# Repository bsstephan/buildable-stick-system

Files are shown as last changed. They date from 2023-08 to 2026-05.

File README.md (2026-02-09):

# The Buildable Stick System

Files for 3D printing and building an arcade stick enclosure.

Have you ever wanted to conjure your own arcade stick out of the ether (well, plastic), or to prototype a new layout or
design before sending it to a custom builder? Do you just love having your space filled with arcade stick enclosures,
because you keep making different variants, colorways, and so on? Or do you simply want a good stick on the cheap, and
know someone or a library with a 3D printer? The Buildable Stick System may be the project for you!

**Join the project IRC channel: [#buildable-stick-system @
Randomus](https://webirc.randomus.net/#buildable-stick-system)!**

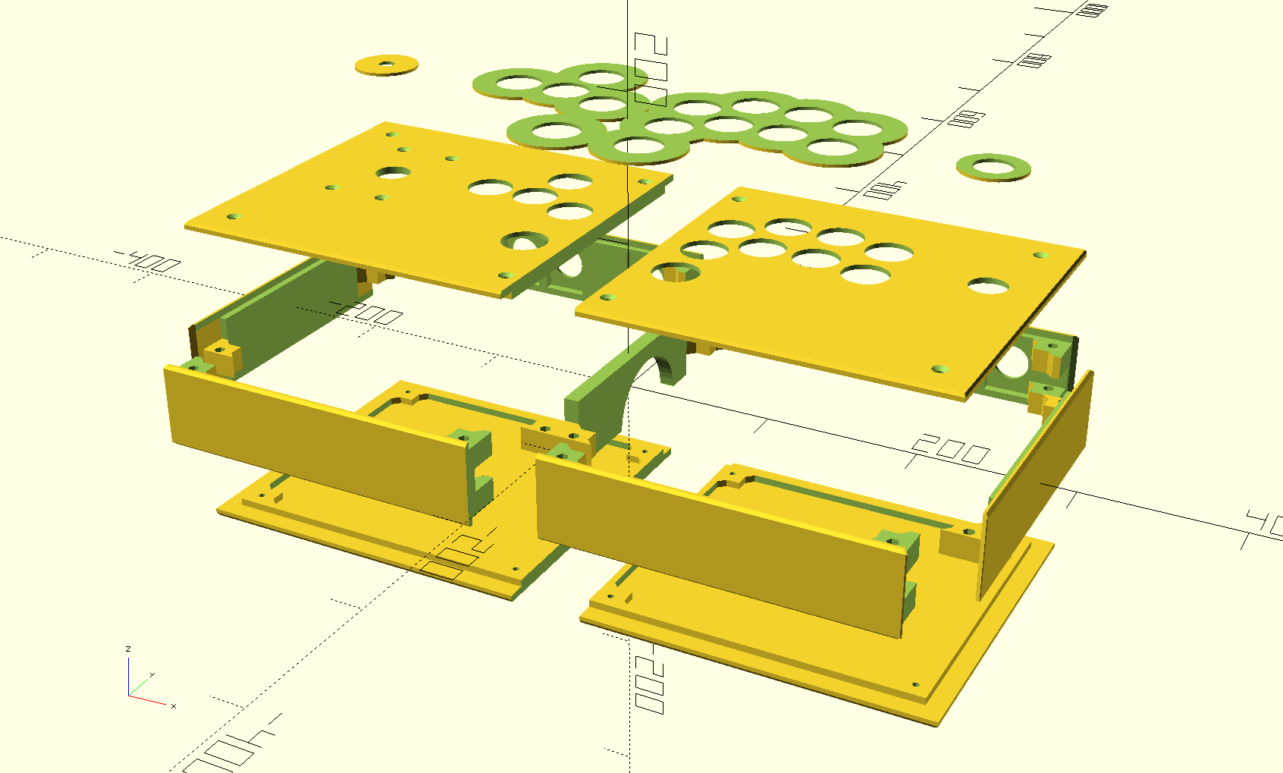
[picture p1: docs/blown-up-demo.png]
An example of stick components displayed in OpenSCAD


[OpenSCAD-based illustration of how the components for an overhang panel-based stick fit together.]

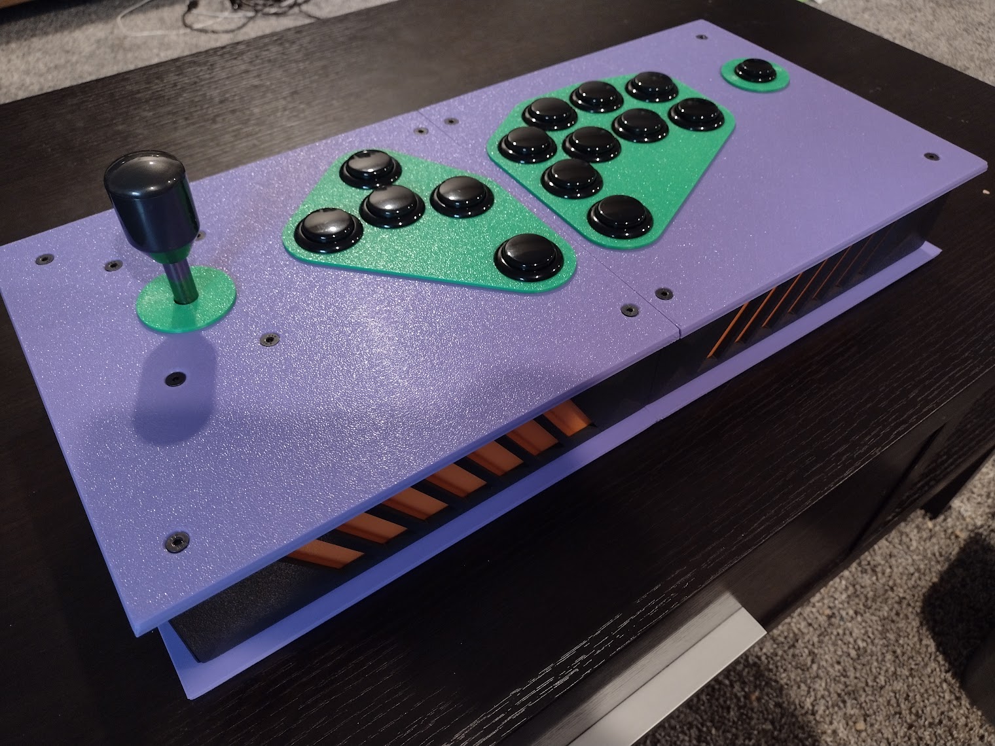
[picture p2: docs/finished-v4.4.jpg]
A photo of a completed stick


[Photo of a completed overhang panel-based stick.]

Originally an attempt to make a couple customized STL files for the [OpenStickCommunity Fightstick
Case](https://github.com/OpenStickCommunity/Hardware/tree/main/Fightstick%20Case), the changes ballooned to fit my
design and became incompatible with that project's components. This should be considered a different project with some
similar DNA, but to stress again, it could not have been done without that project as a guide star. See **Attribution**.

## Designing

No particular arcade stick design is prescribed by this project, instead, SCAD files are provided to choose desired
component objects or create new ones. The OpenSCAD language is essentially a functional programming language, making it
it easy to reuse, alter, and compose objects. If you do not see the object you would like, you can likely create it by
starting with an existing object and constructing what you'd like with new or existing components.

## Usage of Parts

There are a lot of parts to pick from, but there are some structural variants to pay attention to; here's some help
about what the types of parts are and how to use them:

* `frames/`
    * `complete/` --- these are the four walls of the frame as one piece, in a couple variations for combining into
      larger arcade sticks. They are simple to assemble, but you have fewer modularity/customization options, and they
      are harder to print because the physics of the material cooling will probably pull the corners up. They also need
      supports, since the top and bottom of the frame both have trays for panels to go into. Use at your own risk.
    * `pieces/` these are the same four walls (generally speaking) as in the complete frames above, broken out into
      modular pieces to print separately. Because they are separate pieces, you can mix and match colors, and you can
      lay them all face down on the print surface for better adhesion and surface patterns. There are also variants
      here, the "windowed" pieces, for doing two-tone variants and that kind of thing. There are also frame walls pulled
      out to create MCZ TE-style extended sides. There is an interconnect that stands in for the joined inner wall
      between boxes of the overall unit. You need this if you are combining multiple sets of walls, e.g. for a
      two-panel-long stick.
* `panels/`
    * `inset/` --- various panels, all of the same size, that fit into and flush with the frame, making the arcade stick
      top or bottom. Aside from using up a bit of the space for components inside the frame, come with no downsides ---
      they print easily and are a pretty simple shape to tweak and remix.
    * `overhang/` --- overhang panels have their plane extending over the edge of the frame, creating a bit of a
      sandwich look. This is mostly an aesthetic choice, but they sit higher in the frame as well, the main panel being
      over/under the frame rather than within it. This extra space is useful for taller levers. The only downside to
      these is that they aren't as reusable as the inset panels, since the inset panels can go anywhere, but the
      overhang panels must be designed to not overlap with other overhang panels, so you might have to make more custom
      variants depending on where you put things.
* `plates/`
    * Flat pieces used for cosmetic or connective reasons --- decorative plates for top buttons and similar to give
      more color variance and some layers to the arcade stick, some very simple dustwashers, plates that fit rocker
      switches and the like in Neutrik D or 20mm holes, and a lever mount spacer for getting your lever shaft at the
      desired height. You don't *need* any of these, but you'll probably use a few.
* `misc/`
    * Pieces that I haven't organized better (yet) --- odd things and scratch ideas, mostly. There are some decorative
      corners for a bit more height/nicer seams, a sleeve to make smaller hex spacers fit in the hole as they're
      supposed to, things of that nature.
* `extras/`
    * Various experiments and things not directly related to making an arcade stick. At time of writing, there's a
      couple pieces for a little stand for the stick, solely for vanity purposes.
        * `bss-ae/` --- these are pieces for an arcade control panel that fits on the Qanba 2009. See the docs in that
          directory for details.

Feel free to request or contribute to more objects. Additional documentation regarding assembling the stick is available
in `docs/assembly-and-tips.md`.

## Printing

These items all fit on a 256mm^2 print bed; I use a Bambu Lab P1P based on what I've learned from the
OpenStickCommunity. Standard settings seem sufficiently sturdy, but see `docs/printing-and-materials.md` for more
thoughts and settings based on my tinkering with prints.

## Assembling

What you'll need beyond these objects:

* An arcade stick board (I recommend [TheTrain's RP2040 Advanced Breakout
  Board](https://github.com/OpenStickCommunity/Hardware/tree/main/RP2040%20Advanced%20Breakout%20Board))
    * 4 M3 8mm hex bolts to secure the PCB to a panel
* Per frame and panel combo:
    * 4 45mm M4 hex brass standoffs (or equivalent)
    * 8 M4 countersunk hex bolts
        * Overhang panels should use 12-16mm length bolts since they are taller
        * Inset panels should probably use 8-12mm bolts --- some standoffs aren't threaded the whole way, making 16mm
          too long to go flush
        * If making the 45mm standoffs from multiple smaller ones, make sure they have enough length to take your bolts!
* Per frame connection point (only necessary if you are using complete frames and not frame pieces):
    * 8 16mm M4 bolts
    * 8 M4 flange nuts
* For a lever:
    * 4 12-16mm M4 countersunk hex bolts
    * 4 M4 flange nuts
* For Neutrik D connections:
    * 2 10mm M3 hex bolts
    * 2 M3 flange nuts
* Buttons and levers as desired
* Wiring as required

## Rough Costs

This is a rough estimate of the cost to produce one of these sticks, assuming a usual 2-frame design and layout.
Filament masses from Bambu Studio estimates, using Bambu PLA Basic, 20% gyroid infill and 3 wall loops.

* Left and right frame: **$10.42 USD** (208.50g each, as of 2024-02-22)
* Left and right (inset) top panels: **~$6.40 USD** (~128g each, as of 2024-02-22)
* Left and right (non-overhang) bottom panels: **$6.80 USD** (135.99g each, as of 2024-02-22)
* Miscellaneous mounting plates, decorative plates, etc.: **~$1.83 USD** (~73g, as of 2024-02-22)
* 8 16mm M4 bolts to connect the frames: **$0.72 USD** (you can get a pack of 100 on Amazon for $9, as of 2023-09-12)
    * These are only necessary if you are using the whole frames, but as a heads up, the material cost of the
      pieces-based interconnect piece costs around $1, so it's roughly a wash since that's also a frame wall.
* 8 M4 flange nuts to connect the frames: **$0.68 USD** (you can get a pack of 100 on Amazon for $8.50, as of 2023-09-12)
* 4 10mm M3 bolts to connect Neutrik D plates to frames: **$0.40 USD** (you can get a pack of 100 on Amazon for $10, as
  of 2023-09-12)
* 4 M3 flange nuts to connect Neutrik D plates to frames: **$0.34 USD** (you can get a pack of 100 on Amazon for $8.50,
  as of 2023-09-12)
* 8 45mm M4 standoffs to connect panels to frames: **$2.40 USD** (you can get a pack of 10 on AliExpress for $3, as of
  2023-09-12)
    * You could 3D print these too, but you're probably better off with brass ones as they give some weight to the
      stick anyway
    * You can also use a shorter length with longer bolts, or combine multiple standoffs, if either of those yield better
      prices
* 8 16mm M4 bolts to connect top panels to frames: **$0.72 USD** (you can get a pack of 100 on Amazon for $9, as of
* 8 12mm M4 bolts to connect bottom panels to frames: **$0.72 USD** (you can get a pack of 100 on Amazon for $9, as of
  2023-09-12)

With an enclosure coming in around $31, depending on your choices --- say, ~$30 for TheTrain's RP2040 Advanced Breakout
Board, ~$60 for Sanwa buttons and a lever, and ~$20 for miscellaneous connectors and wiring --- you can put a
full-featured controller with an open source foundation together for around $140. Reducing wall and infill settings
will probably save you around $5 of material, and you can probably decide what you want to do from there.

## FAQ

### I get a bunch of warnings on not being able to include files when I open them in OpenSCAD, what do I do?

OpenSCAD pathing is relative to the current working directory by default, which is probably not the `src/` directory.
When you start OpenSCAD, you must either start it from inside the project's `src/` directory, or point it at the path to
the source files via e.g. `OPENSCADPATH=path/to/buildable-stick-system/src/ openscad`.

See <https://en.wikibooks.org/wiki/OpenSCAD_User_Manual/Include_Statement>.

## Miscellany

See the `/docs/` directory for more thoughts too scattered for this document.

## Issues and Limitations

This is a living repository, and as such, there are likely issues with the objects, known or otherwise.
These issues may be fixed in the future; see `TODO.md` for details.

## Development and Contributing

Improvements, variants, new layouts, novel ideas, and etc. are all welcome.

These files are suitable for previewing and rendering in OpenSCAD. They may also work in FreeCAD and perhaps other
software, but they are developed in OpenSCAD, so YMMV otherwise.

This project is hosted at [my personal Git site](https://git.incorporeal.org/bss/buildable-stick-system), but people are
more likely to want to interact with [the GitHub mirror](https://github.com/bsstephan/buildable-stick-system). Feel free
to use either.

I'm reachable on the fediverse, over email, or on Discord, but if you're looking for an option I prefer, I maintain an
IRC channel, `#buildable-stick-system`, on [my IRC network, Randomus](https://randomus.net/) if you would like a place
to hang out and discuss issues and features and whatnot.

## Attribution

### Author and Licensing

Written by and copyright Brian S. Stephan (<bss@incorporeal.org>).

The Buildable Stick System is free software: you can redistribute it and/or modify it under the terms of the GNU General
Public License as published by the Free Software Foundation, either version 3 of the License, or (at your option) any
later version.

The Buildable Stick System is distributed in the hope that it will be useful, but WITHOUT ANY WARRANTY; without even the
implied warranty of MERCHANTABILITY or FITNESS FOR A PARTICULAR PURPOSE. See the GNU General Public License for more
details.

You should have received a copy of the GNU General Public License along with the Buildable Stick System. If not, see
<https://www.gnu.org/licenses/>.

### Lineage

Inspired by the incredible work of [TheTrain](https://github.com/TheTrainGoes) on the [OpenStickCommunity Fightstick
Case](https://github.com/OpenStickCommunity/Hardware/tree/main/Fightstick%20Case), itself based on the incredible work
by [Dash n'Mash](https://twitter.com/Dash_xx_Mash?s=20). Original work Copyright 2023 TheTrain, [licensed under CC BY
4.0](https://creativecommons.org/licenses/by/4.0/).

Made possible by the amazing efforts of [slagcoin](https://www.slagcoin.com/).

### Distributing BSS Sticks

Under the terms of the GPLv3, you must inform the receiver of the "object code" of their rights under the GPLv3. This is
a bit of a gray area for physical objects, but likely applies to distribution of modified or unmodified STL, STEP, etc.
files at a minimum. The easiest way to satisfy the GPLv3 in either situation is to provide a link to the source code
(either the unmodified mainline project, or your copy, with modifications listed in a "prominent notice"); something
like the below should suffice in either electronic or printed form:

> This arcade stick is part of the Buildable Stick System, version X.Y.Z; the source code to this program is available
> under the terms of the GNU General Public License, at [LINK].

## Gallery

More photos.

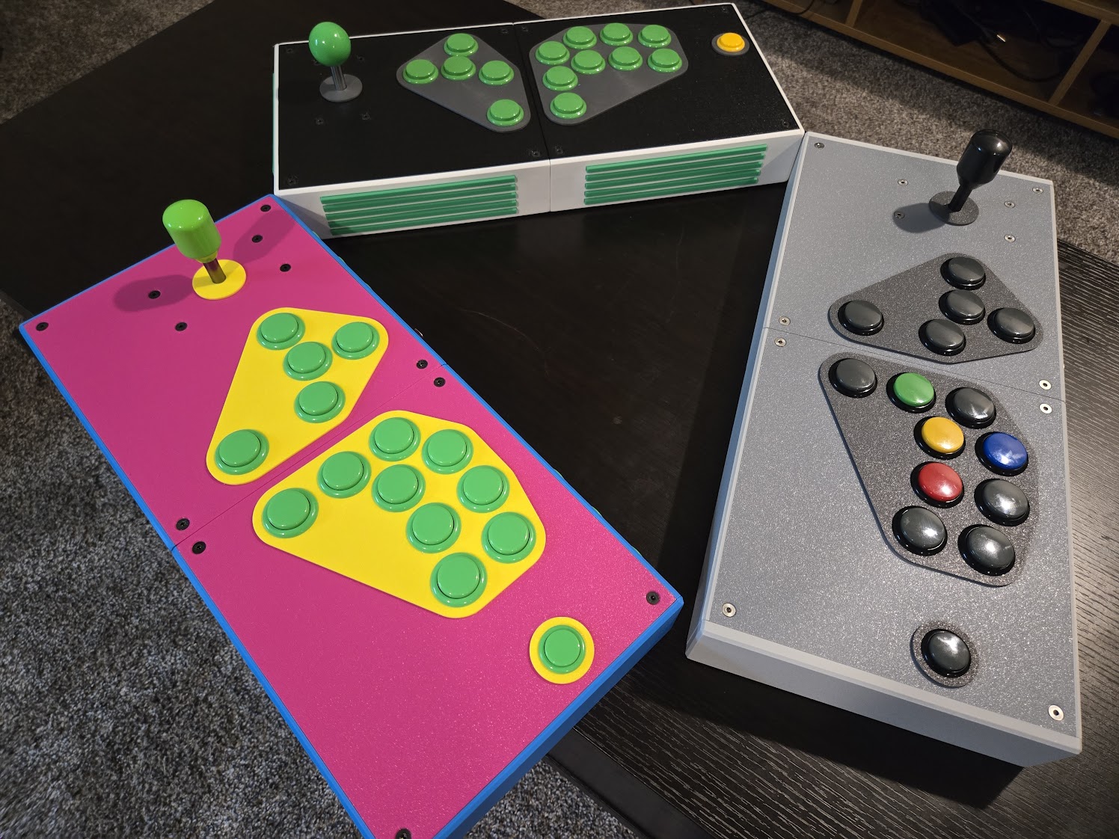
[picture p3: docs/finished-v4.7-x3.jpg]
A photo of three completed sticks


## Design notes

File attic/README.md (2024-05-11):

# The Attic

This directory includes abandoned pieces that I'd like to revisit some time, but I cannot support or recommend using
as-is. Print at your own caution, or better yet, maybe fix them!

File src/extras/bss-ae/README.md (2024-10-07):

# BSS Arcade Edition

Pieces for mounting to a Qanba 2009 in order to create the Buildable Stick System - Arcade Edition.

## Pieces

* 4 `interconnect-x` --- creating the internal support for joining two rows of panels
* 6 `frames/pieces/interconnect` --- (core project) the standard piece for joining two+ columns of panels
* 4 `extended-side-no-back` --- the extended side pieces, flush on the back to connect to each other
* 4 `frames/pieces/extended/front-or-back` --- (core project) the front extended piece
* 2 `extended-back` --- a small piece that fits into the Qanba 2009 "lip" for running cables
* 1 `extended-back-left-mount`
* 1 `extended-back-right-mount` --- extended back pieces that can be mounted to the Qanba 2009 base
* 1 `panel-front-left-mount`
* 1 `panel-front-right-mount` --- blank panels that can be mounted to the Qanba 2009 base
* 6 `panels/inset/panel` --- the rest of the bottom panels
* 4 `panels/inset/` panels of your choice for the front controls
* 2 `panel-three-aux-buttons` --- for aux controls in the back row
* 2 `panel-three-aux-buttons-and-rocker-hole` --- for aux controls and the wired rocker in the back row
* 4 `decorative-plate-aux-control-tight-three-button-cluster` --- for decorating the aux control clusters
* 4 `src/misc/` decorative plates of your choice for the front controls, and similar miscellany
* 4 `mount-spacer` --- making a flush mount between the enclosure and the base

## Hardware

* 32 45mm M4 hex brass standoffs (or equivalent) for each panel/frame compartment
* 64 8-12mm M4 countersunk hex bolts for attaching panels to the compartments
* 4 8-12mm M3 hex bolts and 4 M3 flange nuts for attaching rocker switches to the back panels
* 4 40mm M6 bolts for connecting the enclosure to the base
* 4 M6 flange nuts

## Components

* 2 controller boards, e.g. the RP2040 Advanced Breakout Board
* buttons and/or levers as desired
* necessary wiring

For the rest of the build (e.g. mounting a level to a panel), see the core README.

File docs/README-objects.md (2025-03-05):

# The Buildable Stick System

Files for 3D printing an arcade stick. See `README.md` for the core documentation, this file is specific to distributed
objects.

## Attribution

### Author and Licensing

Written by and copyright Brian S. Stephan (<bss@incorporeal.org>).

These arcade stick parts are from the Buildable Stick System; the source code to this program is available under the
terms of the GNU General Public License, at:

* <https://github.com/bsstephan/buildable-stick-system>, or
* <https://git.incorporeal.org/bss/buildable-stick-system>

See the tags/releases for the version of the source code corresponding to the STLs you received.

The Buildable Stick System is free software: you can redistribute it and/or modify it under the terms of the GNU General
Public License as published by the Free Software Foundation, either version 3 of the License, or (at your option) any
later version.

The Buildable Stick System is distributed in the hope that it will be useful, but WITHOUT ANY WARRANTY; without even the
implied warranty of MERCHANTABILITY or FITNESS FOR A PARTICULAR PURPOSE. See the GNU General Public License for more
details.

You should have received a copy of the GNU General Public License along with the Buildable Stick System. If not, see
<https://www.gnu.org/licenses/>.

### Lineage

Inspired by the incredible work of [TheTrain](https://github.com/TheTrainGoes) on the [OpenStickCommunity Fightstick
Case](https://github.com/OpenStickCommunity/Hardware/tree/main/Fightstick%20Case), itself based on the incredible work
by [Dash n'Mash](https://twitter.com/Dash_xx_Mash?s=20). Original work Copyright 2023 TheTrain, [licensed under CC BY
4.0](https://creativecommons.org/licenses/by/4.0/).

Made possible by the amazing efforts of [slagcoin](https://www.slagcoin.com/).

### Distributing BSS Sticks

Under the terms of the GPLv3, you must inform the receiver of the "object code" of their rights under the GPLv3. This is
a bit of a gray area for physical objects, but likely applies to distribution of modified or unmodified STL, STEP, etc.
files at a minimum. The easiest way to satisfy the GPLv3 in either situation is to provide a link to the source code
(either the unmodified mainline project, or your copy, with modifications listed in a "prominent notice"); something
like the below should suffice in either electronic or printed form:

> This arcade stick is part of the Buildable Stick System, version X.Y.Z; the source code to this program is available
> under the terms of the GNU General Public License, at [LINK].

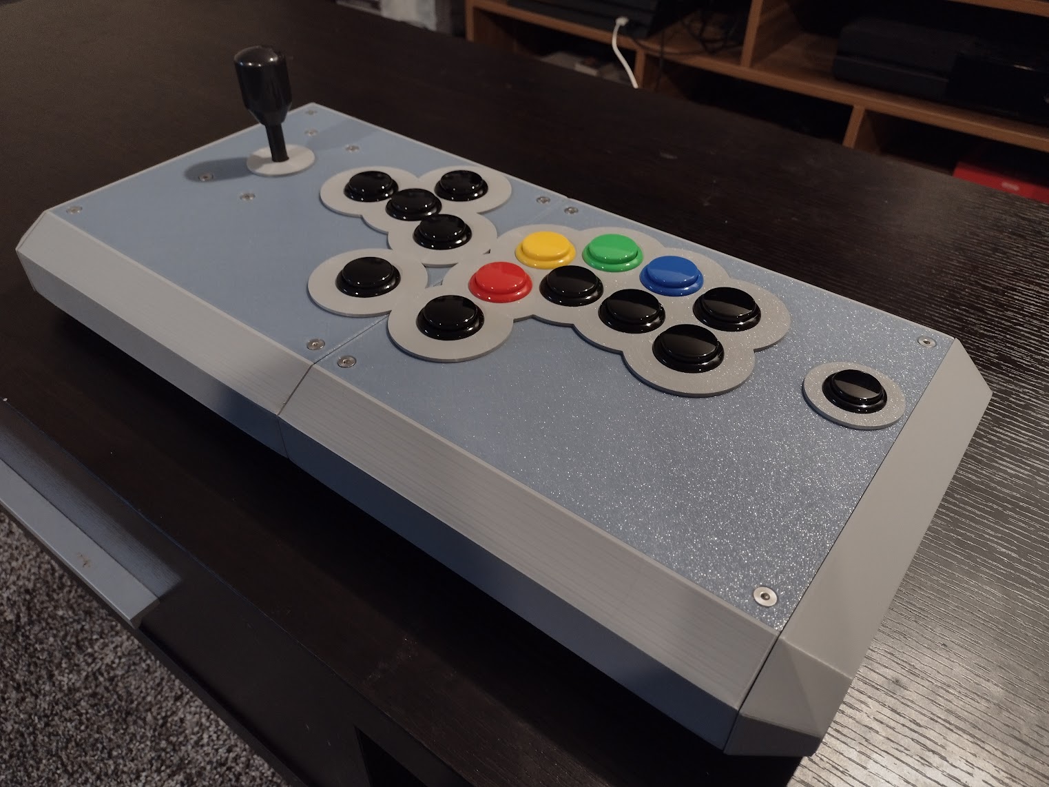
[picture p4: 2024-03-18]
docs/finished-v4.2.jpg

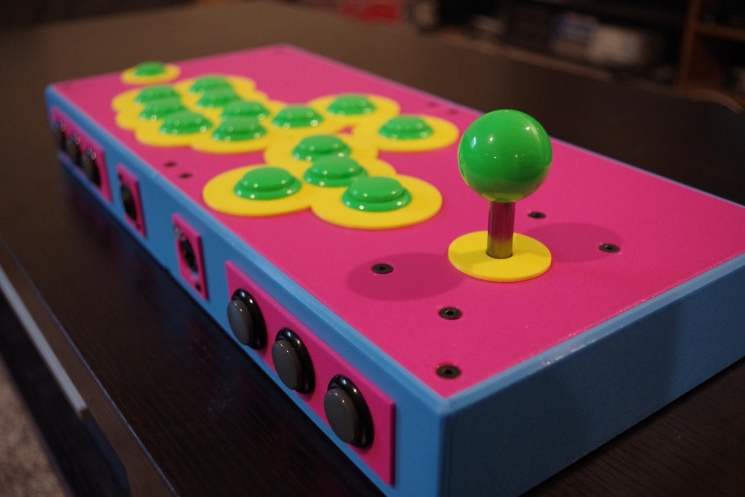
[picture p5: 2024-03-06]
docs/finished-v4.1.jpg

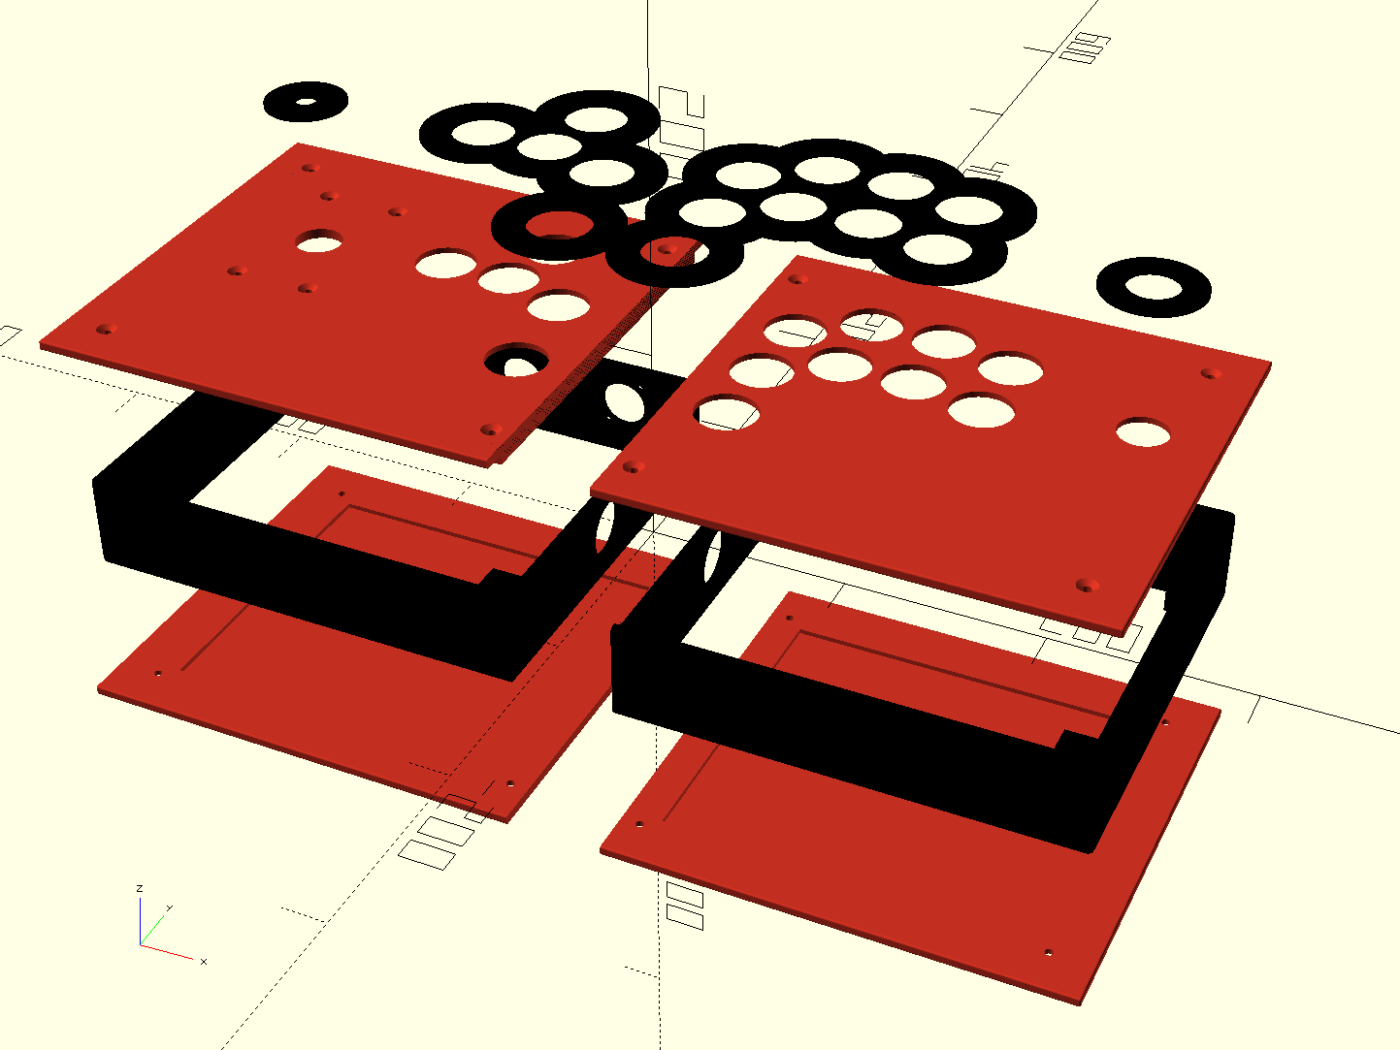
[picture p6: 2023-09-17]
docs/two-panel-example-v3.png

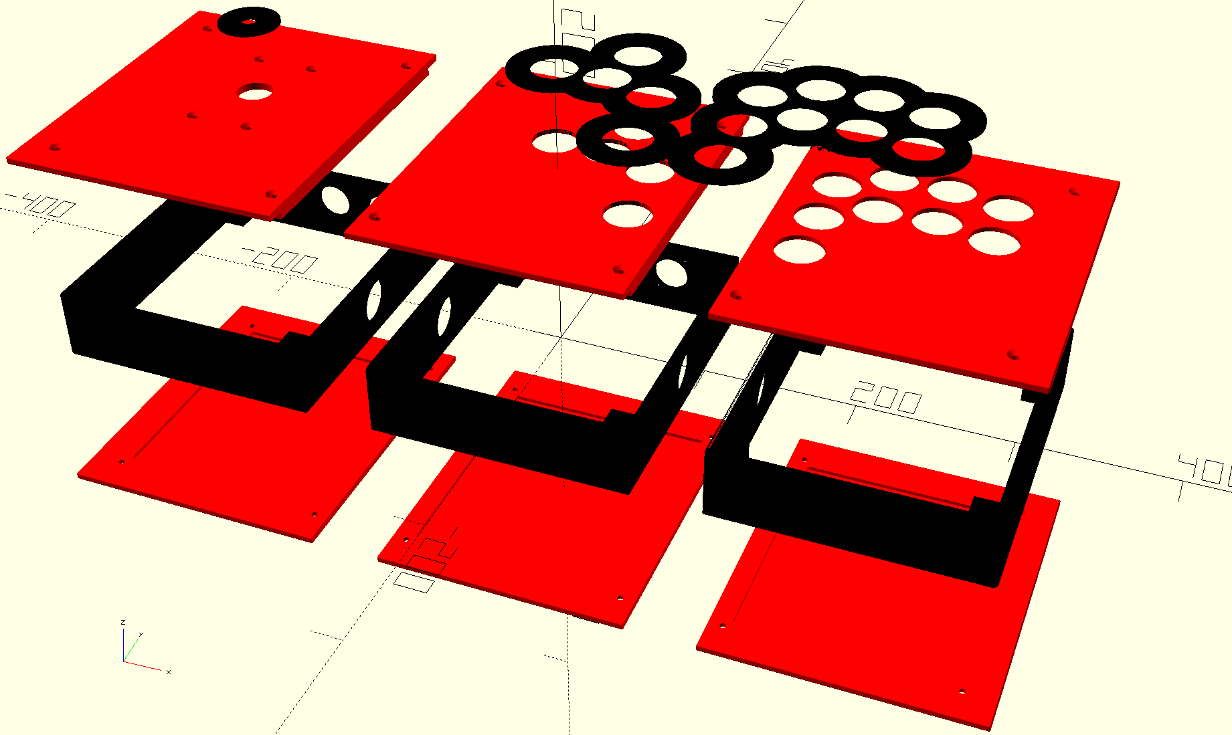
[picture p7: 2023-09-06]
docs/three-panel-example-v2.png

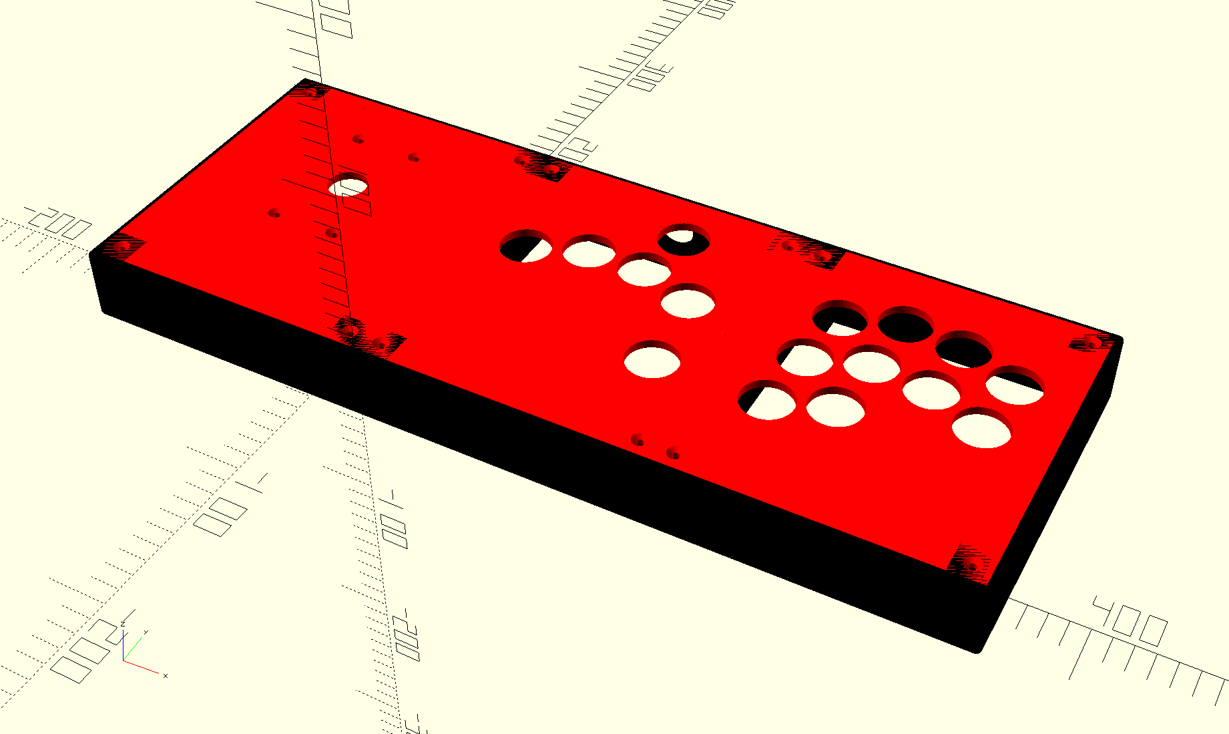
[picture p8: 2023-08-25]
docs/three-panel-example.png

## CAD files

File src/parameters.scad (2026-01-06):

/*
 * SPDX-FileCopyrightText: © 2023 Brian S. Stephan <bss@incorporeal.org>
 * SPDX-License-Identifier: GPL-3.0-or-later
 */


// CONNECTION POINT SIZES


// adjustments
hole_tolerance = 0.15;

// M2
m2_screw_selftap_radius = 0.95;

// M3
m3_screw_selftap_radius = 1.3;

// M4
m4_bolt_radius = 2 + hole_tolerance;
m4_bolt_countersink_radius = 6.1 + hole_tolerance;
m4_bolt_hex_exterior_radius = 3.6 + hole_tolerance;

// M6
m6_bolt_radius = 3 + hole_tolerance;

// 24mm button
small_button_radius = 12 + hole_tolerance;

// 30mm button
big_button_radius = 15 + hole_tolerance;

// carve out space around buttons for screw-in nuts
// slagcoin has screw-in nut diameter at 36mm for 30mm buttons, 29.5 for 24mm buttons
// radius + value below should leave space for the nut and for fingers to grab the nut
button_radius_connector_space = 5;

// standard lever hole
lever_plate_hole = 12;

// neutrik D screw holes
neutrik_d_screw_radius = 1.6 + hole_tolerance;
neutrik_d_radius = 12 + hole_tolerance;


// ELEMENT DIMENSIONS


// JLF mount dimensions
lever_mount_x = 53;
lever_mount_y = 95;
lever_mount_z = 2;

// base frame box. reminder: inside top and bottom (including mounts) are chopped by panel_z for plates
frame_x = 233;
frame_y = 208;
frame_z = 57;

// depth of the "lip" of the frame that the top plate sets into/supports the overhang
frame_wall = 4;

// top plate, which can either be the whole plate ("inset") or the mounting frame for a plate that overhangs
panel_x = frame_x - (frame_wall * 2);
panel_y = frame_y - (frame_wall * 2);
panel_z = 5;

// some dimensions for frame pieces, useful in doing some intersections and chopping
frame_piece_x_x = frame_x - (frame_wall * 2);	// essentially panel_x, yes
frame_piece_y_y = frame_y;			// the whole y of the frame, yes

// degree to which the extended frame pieces stick out from the end of the frame
frame_extension_x = 25;
frame_extension_y = 25;

// this sinks the bottom and top of the frame inward a bit, and is used to math out two shapes
// when creating the frame box / overhang panel
frame_bevel_height = 1.25;
overhang_panel_bevel_height = 1;

frame_center_to_neutrik = 70;

// width of the column in the frame corners to support the hex bolt
frame_mount_column_width = 20;

// per neutrik (mm)
neutrik_panel_thickness = 3;

// inside the frame
inner_frame_z = frame_z - (panel_z * 2);

// "windowed" pieces chop out the inner wall of the frame as a separate piece in order
// to print it a different color/way/style. to improve friction fit, it is only the below
// value scale of the whole wall, so that the rest of the wall is retained on the outer
// piece, which helps clamp the two together (and helps the panels clamp it all)
inner_frame_z_decorative_scale = 0.95;

// how much the top plate x/y is expanded to overhang the frame
// note that this is relative to the top plate (so the wall is added back)
panel_overhang_amount = 8.5;
overhang_panel_x = panel_x + (frame_wall * 2) + (panel_overhang_amount * 2);
overhang_panel_y = panel_y + (frame_wall * 2) + (panel_overhang_amount * 2);

panel_to_frame_point_offset = 10;
panel_to_frame_point_x = (panel_x/2) - panel_to_frame_point_offset;
panel_to_frame_point_y = (panel_y/2) - panel_to_frame_point_offset;

// frame interior that supports the top plates
panel_support_width = 5;

// additional button radius for decorative panels, etc.
decorative_radius_scale = 1.75;
jumbo_decorative_radius_scale = 2;

// decorative wall cutout parameters
// thicker than the actual base wall to account for the longish pieces
wall_cutout_depth = frame_wall * 3;

// decorative slash parameters
slash_inner_displacement = 10;
slash_width = 15;
slash_height = frame_z-panel_z*3;

// dustwasher parameters
jlf_dustwasher_radius = 19;
jlf_shaft_inner_radius = 4.55;

lsx_nobi_dustwasher_radius = jlf_dustwasher_radius;
lsx_nobi_shaft_inner_radius = 5;

shaft_position_tolerance = 2;

// stand dimensions to display a stick
stand_x = 5;
stand_y = frame_z;
stand_z = 15;

// oled cutout stuff
ssd1306_x = 23;
ssd1306_y = 12;
ssd1306_z = 1;
adafruit_pid_326_oled_ssd1306_cutout_x = 30;
adafruit_pid_326_oled_ssd1306_cutout_y = 32;


// LAYOUTS


sega_2p_column_2_offset = 30.5;
sega_2p_column_3_offset = sega_2p_column_2_offset + 36;
sega_2p_column_4_offset = sega_2p_column_3_offset + 36;
sega_2p_column_5_offset = sega_2p_column_4_offset + 36;

// this offset is from the left edge of the panel
sega_2p_column_1_left_panel_edge_offset = 28.06;

dir_arc_30mm_column_2_offset = 33.8;
dir_arc_30mm_column_3_offset = dir_arc_30mm_column_2_offset + 34.8;
dir_arc_30mm_row_2_offset = 57.2;
dir_arc_30mm_row_3_offset = dir_arc_30mm_row_2_offset + 12.9;
dir_arc_w_30mm_row_4_offset = dir_arc_30mm_row_3_offset + 34.5;

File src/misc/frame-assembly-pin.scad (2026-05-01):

/* Fit a pin for the assembly holes.
 *
 * SPDX-FileCopyrightText: © 2026 Brian S. Stephan <bss@incorporeal.org>
 * SPDX-License-Identifier: GPL-3.0-or-later
 */
include <parameters.scad>
include <components.scad>

// adjust the pin to have a good friction fit based on parameters
pin_fit_scale = ((m4_bolt_hex_exterior_radius-hole_tolerance)*2)/(m4_bolt_hex_exterior_radius*2);

module frame_assembly_pin() {
	difference() {
		scale([pin_fit_scale, pin_fit_scale, 0.95]) resize([0, 0, inner_frame_z]) frame_hex_bolt_hole();
		scale([0.8, 0.8, 1]) resize([0, 0, inner_frame_z]) m4_hole();
	}
}


frame_assembly_pin();

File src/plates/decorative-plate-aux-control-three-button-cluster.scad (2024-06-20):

/*
 * SPDX-FileCopyrightText: © 2023 Brian S. Stephan <bss@incorporeal.org>
 * SPDX-License-Identifier: GPL-3.0-or-later
 */

include <parameters.scad>
include <components.scad>
use <neutrik-d-plate.scad>

module aux_control_three_button_cluster_decorative_plate() {
	difference() {
		hull() {
			translate([-44, 0, 0]) neutrik_d_plate();
			translate([44, 0, 0]) neutrik_d_plate();
		}
		translate([0, 0, -10]) aux_control_three_button_cluster();
	}
}

aux_control_three_button_cluster_decorative_plate();

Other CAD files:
src/extras/bss-ae/decorative-plate-aux-control-tight-three-button-cluster.scad
attic/extras/tower-of-hovering-power-mount.scad
demo/all-together-demo-extended-with-windows.scad
demo/all-together-demo-extended.scad
demo/all-together-demo-solo.scad
demo/all-together-demo.scad
demo/blown-up-demo.scad
src/bottom-panel-no-overhang.scad
src/bottom-panel-solo-concave.scad
src/bottom-panel.scad
src/components.scad
src/extras/bss-ae/extended-back-left-mount.scad
src/extras/bss-ae/extended-back-right-mount.scad
src/extras/bss-ae/extended-back.scad
src/extras/bss-ae/extended-side-no-back.scad
src/extras/bss-ae/interconnect-x.scad
src/extras/bss-ae/mount-spacer.scad
src/extras/bss-ae/panel-front-left-mount.scad
src/extras/bss-ae/panel-front-right-mount.scad
src/extras/bss-ae/panel-three-aux-buttons-and-rocker-hole.scad
src/extras/bss-ae/panel-three-aux-buttons.scad
src/extras/stand-base.scad
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

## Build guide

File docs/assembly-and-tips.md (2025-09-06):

# Assembly and Tips

These are the parts you need and instructions for creating a simple two panel arcade stick. The end product is a
rectangular prism roughly 18" long, with ample space for back buttons and enough top panel space for almost any layout
you can imagine. There are more pieces and designs to experiment with, but this will get you an awesome "standard"
build.

## Parts for a Basic Enclosure

The pieces you need to print (all colors to your taste):

* **The base frame:** `frame/pieces/front-or-back.stl` x2 + `frame/pieces/front-or-back-aux-and-neutrik.stl` x2 +
  `frame/pieces/interconnect.stl`. This creates a large "H" with six 24mm button holes and two Neutrik D holes on the
  back, which can mount USB connectors or rocker switches, or be covered if not used. All four of the front or back
  pieces connect to the interconnect piece, which creates one frame out of the individual pieces, and also adds some
  support to the center of the enclosure. The interconnect has a large hole that can either make wire routing easier, or
  leave space in the center for button layouts that span it.
* **The frame sides:** `frame/pieces/side.stl` x2. These cap the "H", completing the overall frame.
* **The top:** `panels/inset/[LAYOUTS].stl`. These panels go on the top of the frame and are where you mount all of your
  main buttons and levers and whatnot. There are a couple layouts whose panels are meant to be paired (e.g.
  `shiokenstar-left-panel.stl` and `shiokenstar-right-panel.stl`), but usually you simply pick a left panel (e.g.
  `lever-panel-with-mount.stl`) and right panel (e.g. `sega-2p-panel.stl`) based on what you want. Note that one of your
  choices should be "with mount", which is where the usually-sized PCB will screw into inside the box.
* **The bottom:** `panels/inset/panel.stl` x2. Other than being the color of your choice, these just close the box.
  You could put foam pads or something on these if you wanted.

The above gets you the basics. Some common things you may also want:

* **Mounting Neutrik connectors:** Neutrik D connectors can mount flush to the inside of the frame, but you can choose
  to have a little decorative plate (`plates/neutrik-d-plate.stl` for added depth or color choices on the outside of the
  frame, if you'd like.
* **Mounting a 24mm switch:** a rocker switch can also be mounted in the Neutrik D connector, but it needs to be placed
  into a `plates/neutrik-d-plate-24mm-hole.stl` plate, and the plate mounted to the frame.
* **Flair for the auxillary buttons:** the three buttons in a row on the back of the frame can also get some style, just
  place a `plates/decorative-plate-aux-control-three-button-cluster.stl` between the buttons and the frame. This only
  works for screw-in buttons.
* **Flair for the top buttons:** same as above, a decorative plate for top panel layouts --- e.g.
  `plates/decorative-plate-sega-2p.stl` --- can be sandwiched between the buttons and panel to add some style. This also
  only tends to work on screw-in buttons.
* **Dustwashers/flair:** same deal, if you want to print one, use e.g. `plates/dustwasher-jlf.stl`.

## Putting a BSS Stick Together

Assembly of a stick is pretty straightforward, but there are some choices that can make it easier or harder. The
following is the most consistent way I've found to put one together.

1. Prepare the frame pieces: this is your best shot to get the e.g. Neutrik plates for the USB mount, SPDT switches, etc.
   installed, so do it now, and give them a good tighten. You shouldn't need to adjust these again, so finish their
   installation while the pieces are free.
    1. You could also do the decorative plates and related buttons, but it might be just as well to leave those for step 7,
       just to make sure the buttons don't get in the way of other buttons or a lever or so on.
2. Start the top panels: you want both to get the components installed now when it's easy, and to make sure that the
   overall assembly works with your components, so again get your buttons, lever, etc., in place. You can secure them at
   this point.
    1. If you are using a button decorative plate that spans two panels --- e.g.
       `plates/decorative-plate-dir_arc-plus-w-30mm-and-sega-2p-plus-one` --- take care to align the two panels as tightly
       as possible, and accurately, as they will be hard to adjust once everything is secured and in the frame.
    2. If using a lever, don't forget the lever mount spacer --- `plates/lever-mount-sanwa-seimitsu` --- if you want it,
       and tighten those mounting bolts now as well.
3. Create the frame box by combining your frame piece parts, box or extended, together. This will be relatively stable
   just via friction fit.
4. Rest the frame top-up on a desk, and put the standoffs through the holes. This will probably be tight, and you may
   even need a rubber mallet or similar to drive the standoffs through the holes.
5. Insert the top panels into the frame.
6. Insert the bolts for the top panels, make any last adjustments, and tighten them.
7. At this point you have an open box with access to all your components. Do all of your wiring.
    1. Tighten the buttons and etc. if you didn't in step 2.
8. Insert the bottom panels into the frame.
9. Insert the bottom bolts for the bottom panels, and tighten them.

In the end, this should be extremely sturdy. None of the frame or panels should be loose at all, and you should be able
to move, flip, gently toss, etc. the stick without anything moving or feeling loose.

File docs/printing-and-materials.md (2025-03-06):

# Printing and Materials

bss's random thoughts and notes on the actual printing of the Buildable Stick System.

## Printing Settings

My preferred settings are 3 wall loops with 25% gyroid sparse infill. This gives the models a bit more weight and
strength against bowing forces, but something more default, like 2 wall loops, 15% grid sparse infill, is fine and does
not lead to a weak enclosure.

### Supports and Positioning

All of the parts are designed to be printed outside-face-down. The bevels are at an angle (45 degrees) that should print
fine with no supports. Make sure everything is aligned properly on your plate so that the flat face you will look at the
most is on the bottom.

The only exception to this is the interconnect piece(s), which are not visible and need a support to print. Maybe one
day I'll rejigger these.

### Working With Flatness

A lot of the pieces are long and flat, so I recommend really dialing in your printer settings. The frame pieces make
corner curling of the frame less of a problem, but you may still get it on the panels and the beveled frame pieces.

#### Bottom Layer Notes

Considering the visible layer (usually, the bottom layer) pattern is ideal. Monotonic prints fast but creates long,
uniform lines that create reflection patterns on long, flat surfaces. This can be especially distracting for the top
panels and their decorative plates, since they're what you're looking at 90% of the time, and the holes break up a
perfect pattern, making the long lines stand out even more.

Some specific parts are worth some additional notes:

* **Top panels:** using a non-uniform pattern reduces if not eliminates the problem of the surface catching the light,
  but for some patterns, it may come at the expense of time.
    * **Avoid:** monotonic.
    * **Good for the time:** Archimedean chords create the look of a circular ripple radiating out the center, and
      depending on the material, you may not even notice it much, so it's a pretty good look/speed balance.
    * **Great if you can wait:** hilbert curve leaves no discernable pattern on most materials, but some high gloss,
      high contrast materials may show the winding pattern at some angles --- consider Archimedean chords for these.
* **Circle-centric decorative plates:** simple ones could be fine in whatever, but the ones for action buttons end up
  having lots of weird interaction points.
    * **Avoid:** none; monotonic doesn't look *good*, but the plates don't have enough surface area for the pattern to
      stand out too much.
    * **Decent:** concentric is generally good, but you can get some pitting when the pattern radiating away from
      buttons collides with other patterns, because none of the geometry lines up well.
    * **Great:** Archimedean chords, just crank up the infill/wall overlap to avoid pits on the edges.
* **Frame walls with Neutrik or aux button cutouts:** a reduced but similar problem with the action button decorative
  plates, the circles near each other create weird interactions with the walls.
    * **Avoid:** concentric, again, has problems with pitting where geometries clash.
    * **Decent:** monotonic is pretty decent here, and you probably won't look at the sides too much, so maybe it
      doesn't bother you.
    * **Great:** Archimedean chords again, with the same infill/wall overlap as decorative plates.
* **Flush frame walls:** you can pretty much do whatever you like here.
    * **Great:** concentric produces an interesting pattern and you won't have collision problems in a rectangle.
    * **Essentially great:** Archimedean chords yet again, you may just not like the pattern as much as the end result
      of concentric.

The Archimedean chord pattern is a good default and prints awesome parts, with the only exception being the top panels,
which benefit from using a Hilbert curve initial layer pattern instead, though you may be happy enough with Archimedean
chord.

## Materials

Some notes on PLA brands, usages, etc.

### Bambu Lab PLA

#### Basic

* In general, nice texture, but under direct light, you can see a bit of the infill pattern through the walls. Not super
  distracting, but it's there.

##### White

* Walls are practically translucent, you can almost always see the infill. 3 wall loops and a varying infill pattern
  definitely help here.
* Looks perfectly good for thin things like the Neutrik plates, decorative pieces, that kind of thing.

#### Matte

* I don't like the texture as much, but they do produce nice non-primary color colorways, and you don't see the infill.
* Seems like their plastic treatment leaves some plate residue, so be better about cleaning it or you'll get ghosts.

### Hatchbox PLA

* **Blue:** very blue. Wife likes it.
* **White:** more opaque than the Bambu PLA mentioned above, makes a pretty decent (still slightly translucent) frame.

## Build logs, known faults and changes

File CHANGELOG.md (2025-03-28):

# CHANGELOG

Included is a summary of changes to the project, by version. Details can be found in the commit history.

## v4.7.1

### Fixes

* Hull-based decorative plates were accidentally grown in v4.7.0 due to ye olde refactoring. They are back to the
  dimensions they should be (give or take) because there was an underlying bug in how they were geometried pre-v4.7.1.
* The docs/ directory in the build now includes the images referred to, especially in the README.

### Miscellaneous

* Some README tweaks, including another demonstrative photo.
* The build creates both a ZIP of everything, including docs, for humans to download, and also a ZIP of *just* the STLs,
  to ease uploading to Printables.

## v4.7.0

### Features

* Inner wall pieces where the horizontal stripes jut through the horizontal stripe windows have been added, these look
  decent and avoid the outer wall feeling extremely flimsy. This piece uses a "longish" front/back piece which isn't
  retained as a separate piece, because the latter is not meant to be printed itself.
* I somehow went this whole time without creating a simple Sega 2P layout panel and decorative plate; those have been
  added.
* Prototype (still literally a bit rough) braces for the corners and middle have been added. These pieces cover up the
  seams of the frame, and add some visual depth and distinction, but are not for everyone. YMMV.
* A new "superplate" of the "directional arc + W" plus "sega 2P nine" layouts combined has been added, this is a piece I
  ended up not using in a build, but it functions as well as any of the plates, so why not.

### Improvements

* Visible round edges have been made more round.
* The single-24mm-button decorative disc has been shrunk a bit, since (IMO) it stood out a bit too much relative to the
  button.
* The "longish" extended side has been made a bit simpler to construct.
* The side piece construction has been reworked, making it a bit simpler to construct and reducing the build complexity,
  though preview mode still complains about 2-manifold errors.
* The assembly documentation has been cleaned up, with more pieces explained a bit better as well.
* Dustwashers got some small updates to shrink the size of the disc to the normal JLF dustwasher size, and to fit the
  shaft a bit tighter without obstructing the lever's ability to... be a lever.

### Miscellaneous

* The build has been improved to error when there are issues in the .scad files, to keep me from making bad packages.
* The back pieces are aligned properly in the all together demo.
* Updates to the docs on my preferred printing settings.
* README updates following the previous releases' reorganizations.
* Objects README update to add attribution to TheTrain.

## v4.6.0

### Features

* All frame pieces were updated to have flush edges, a la the "extended" sides, rather than the seam between the
  front/back and the sides being at a 45 degree angle on some pieces, with the latter meaning that we were maintaining
  two (complicated) duplicates of the same pieces because both 45 degree and 90 degree angles were necessary. This does
  not affect the look of the build much, but simplifies the print and the maintenance of the project.
* A slightly-extended flat side piece was added, to add just a bit of length to the overall build.

### Improvements

* One more slash has been added to the frame pieces, just for more interesting visuals.
* The rectangle plates' positioning was tweaked slightly.

### Fixes

* The frame solid was very slightly shorter than it should have been as the corners relied on cylinders. The core solid
  is now at its proper dimensions.

## v4.5.0

### Features

* Many components for the Buildable Stick System - Arcade Edition --- pieces to create a control enclosure for the Qanba
  2009 base! These pieces live in `extras/bss-ae/` but do use some parts from the base project; check that subdir's
  README.
* Created a Sega 2P 11 button layout, basically following the curve of the fourth column and adding a fifth, plus one
  extra button
* More decorative plates, this time square ones for an NES-styled project.

### Improvements

* Button layout positions for Sega 2P and directional arc layouts have been parameterized.
* The decorative plates for the directional arc + W and Sega 2P 9 layout have been split into two files, since there was
  no reason to keep them as one with multiple pieces anymore.
* Tweaks to the horizontal stripes in order to get them to print better.
* Renamed "Sega 2P plus one" to Sega 2P 9, following the pattern of the 11 layout.

### Miscellaneous

* Renaming of extended side pieces to fit the front/back idiom.
* Cleanups to the demos.

## v4.4.3

### Features

* Windowed frame wall pieces were made for the "clean" front/back walls that line up with the extended sides.

### Improvements

* The inner wall piece has been thickened, bringing its surface closer to the end of the outer wall windowed frame
  pieces, making the window less deep and the inner wall easier to see.
* The inner wall piece has been shrunken on the Z in order to leave some material on the outer wall and thus improve the
  friction fit and clamp of the outer wall piece, which was too weakened by the unsupported top and bottom otherwise.

### Miscellaneous

* Documentation updates, especially around the printing of parts.
* Corrected the names of some pieces that were accidentally duplicated from the file they were copied from rather than
  what they were, or otherwise didn't match the standard pattern (such as it is).

## v4.4.2

### Bugfixes

* Fix a regression with the small button screw-in space cutting into the frame wall supports. The screw-in space is
  potentially more important for some nuts than the thickness of the frame wall supports, so the latter have been
  thinned slightly.

## v4.4.1

### Features

* A new lever + Sega 2P 6 button panel has been added. The overhang version hadn't been updated in forever, but the
  inset panel moved stuff around in a way that allowed a couple aux buttons to fit in, so those have been added to the
  overhang panel as well.
* A horizontal stripe frame windowed piece has been added. YMMV may vary a bit on this vs. an empty window --- you can
  see less of the inner object with the stripes, but it's a bit more stable.

### Improvements

* The frame wall slashes have been made a bit more reusable.
* The area around button holes for screw-ins has been tweaked to be a bit smaller for 30mm buttons and a bit larger for
  24mm buttons.

### Miscellaneous

* A bottom overhang panel was positioned incorrectly in the demo file; this has been fixed.
* Added a demo of the one-panel overhang lever + 6 button stick.

## v4.4.0

### Features

* New "windowed" frame box walls have been added, which allow for seeing through the outer wall to something else, such
  as an inner wall of a different color, or for people who like showing off their wiring, nothing.
* An attempt at a two-panel "shiokenstar" layout has been added.
* The "plates" decorative plate for my favorite layout was altered since I wasn't using it anyway.

### Improvements

* The frame routing hole, in either the whole frames or the interconnect, is a semicircle on one side, making it easier
  to wire (and rewire) a completed arcade stick, and it also makes button layouts that span the connection point more
  possible.
* Less of the inner wall is cut out for e.g. Neutrik and aux buttons now, removing the possibility for inset panels to
  allow for a tiny bit of light to seep the cracks and giving panels a bit more support.
* The piece-based frame walls now meet at 45 degree angles at the corners, which makes for fewer print anomalies to
  catch your hand or clothing on. These 45 degree angles are not used for the TE1-style extended panels, which still
  meet at 90 degree angles.
* All of the core arcade stick parts, and extras, have been reorganized and renamed into subdirectories that make their
  purpose more obvious. This also makes it clearer what you're looking at when looking at the project file structure.
  Documentation was updated throughout for this change.

### Miscellaneous

* A stand for showing off inset-based sticks has been added to extras. This may get more love in a future release.
* The blown up demo now uses frame pieces, as these are quickly becoming the standard build.
* Cleanups to CONTRIBUTING.md
* Demos have been given their own place in the repository.
* The Makefile has been altered to use a Python script to build the files, due to the complexity of reorganizing the
  project into subdirectories.
* An abandoned floating stand has been moved into the attic --- it barely works right.

## v4.3.x

This finally removed the posts added to the panels introduced in v4.0.

## v4.2.x

This added TE1-like bevels to the repository, which look pretty neat.

## v4.1.0

Having improved the internals in v4.0.0, this broke out the frame into modular pieces, making them easier and more
reliable to print, with only a trivial effect on the overall stability of the stick. This also made the bottom panels
identical to the top, easing reuse.

## v4.0.x

This was an experiment that didn't survive scrutiny to add more posts to the frames and panels, in order to improve the
friction fit, but it really just make the whole thing more obnoxious to work with. However, this redesign also came with
some key improvements to the construction of the stick, which has made the subsequent releases easier to work with.

## v3.3.x

Largely a cleanup, this improved the component reuse and added more complete licensing information to the project.

## v3.2.x

This improved the frame height to accommodate more levers in inset panels, along with some cleanup.

## v3.1.x

This added panels for more layouts with more buttons, establishing my go-to of a lever, a directional arc with an extra
button in a W-as-in-WASD position, and a Sega 2P-inspired 9-button action button layout.

## v3.0.x

I think the project really took shape at this point, as it resized the panels and frames to accommodate a two-panel
layout for nice, long sticks.

## v2.0.x

This added the overhang plates to the mix, while still sticking to the three-panel design. It also started adding
dustwashers and decorative plates, which improved the aesthetics of the project.

## v1.0.x

This was a simple three-panel stick that was somewhat ridiculously long, but worked, and built a lot of the foundation
for the project. Its start as being inspired by the Open Stick really showed at this point, but things were coming
together.

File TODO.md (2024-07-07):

# TODO

Notes for "next time".

## v4.x

* Engraving some cosmetic stuff? Or maybe a place to mount other plates on the top?

## v5

* Finishing the build123d rewrite?

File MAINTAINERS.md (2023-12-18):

# Maintainers

This file contains information about people permitted to make major decisions and direction on the project.

## Contributing Under the DCO

By adding your name and email address to this section, you certify that all of your subsequent contributions to the
Buildable Stick System are made under the terms of the Developer's Certificate of Origin 1.1, available at `DCO.txt`.

* Brian S. Stephan (<bss@incorporeal.org>)

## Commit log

2023-08-16 test panel for this printed pretty well
    maybe the tolerance could be tightened just a bit, but other than that,
    seems like a pretty good start
    [components.scad, top-left-panel.scad]
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2023-08-16 small tweaks to hole sizes
    shouldn't be enough to reprint the top left panel yet, just tweaking
    based on the frame and test runs
    [components.scad]
2023-08-17 successful version of the left frame
    print seems aligned with the top plate, hole sizes look right, still
    need to pair it with a true middle frame
    [components.scad, left-frame.scad]
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2023-08-17 make the noir and sega 2p panels modules
    mostly so I can use them in other .scad files to compare layouts and
    that kind of thing
    [top-panel-namco-noir-plus-one.scad, top-panel-sega-2p-plus-one.scad]
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2023-08-18 tiny rename for the lever base plate
    this might move into components (while not adjusted) at some point
    [top-panel-left-lever.scad]
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2023-08-18 middle frame mostly ok, but I forgot to check neutrik panel thickness
    [components.scad, frame-middle.scad]
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2023-08-18 ethercon (and probably other neutrik Ds) need the wall thinner
    to avoid overhang, this shrinks the overall case by 2mm on the x and y,
    as this number was somewhat arbitrary
    [components.scad, frame-middle.scad]
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2023-08-20 properly center frame mounting holes
    noticed this after my first print, it's a fix for v1 but I don't think
    I'll bother reprinting my stuff yet
    [frame-left.scad, frame-middle.scad]
2023-08-21 shrink the JLF mount panel height by 1mm
    trying to shave a couple mm off the design to make room for this Seimitsu SEL-70X-F
    [components.scad, top-panel-left-lever.scad]
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2023-08-21 panel for 30mm "directional arc" buttons + W + one extra
    the extra could be mapped to L3 or soemthing like that, for SF6 or other
    weirdos
    [components.scad, top-panel-dir_arc-plus-w-30mm-plus-one.scad]
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2023-08-25 solve for 24mm/30mm snap-ins
    [components.scad]
2023-08-25 a one-panel 24mm dir arc + action buttons layout
    (you can fit 6! not bad!)
    [components.scad]
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2023-08-26 squish a decent all buttons layout onto one panel
    this uses the new raised panel look, I'm trying it out but haven't
    updated the other top panels yet until I'm sure I like it --- it'll mean
    a lot of chopping
    [components.scad, top-panel-solo-dir_arc-24mm-combined.scad]
2023-08-27 standalone frame, with tweaks to the frame as a consequence
    * frame width has been reduced in order to leave more space and have
    sunken buttons somewhat accessible
    * the cutout for neutrik mounts has been reduced and moved into the
    holes themselves, to do this more modularly and restore some support
    [components.scad, frame-solo.scad]
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2023-08-27 fix the frame box width, which was too thin bc math is hard
    [components.scad]
2023-08-28 fix the frame support box again
    math is even harder when you're not using the right variables
    [components.scad]
2023-08-28 bring 5 mm back to the frame
    to accommodate quick connects, levers, etc.
    [components.scad]
2023-08-28 squeeze dir. arc + W w/8 buttons on one panel
    it's a tight squeeze; fits in the frame, but frame buttons/quick
    connects maybe a problem
    [components.scad, top-panel-solo-dir_arc-plus-w-24mm-8-button.scad]
2023-08-29 make a bottom overhang plate
    slightly different than the top since there's no inset, so no need for
    that frame or the posts
    [bottom-panel-solo-concave.scad, components.scad]
2023-08-29 go back to three neutrik D mounts on the solo frame
    this (barely) works
    [frame-solo.scad]
2023-08-29 rename side chopper, going to be used for more than just frames
    [components.scad, frame-left.scad, frame-middle.scad]
2023-08-30 remove unused, unnecessary panel with no concave
    rename bottom panels now that concave is normal
    [bottom-panel-concave.scad, bottom-panel-solo.scad, bottom-panel.scad]
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2023-08-30 center the button panels and their layouts
    I can refactor the double translation away at soem later point
    [components.scad, top-panel-dir_arc-plus-w-30mm-plus-one-with-mount.scad, top-panel-dir_arc-plus-w-30mm-plus-one.scad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]
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2023-08-30 consolidate button hole and wider cylinder into one object
    nothing was materially using the non-snap-in cutout anymore (except for
    the frame which wasn't updated since removing the bigger cutout
    rectangle, so I fixed that), and I want to use it for a template thing
    I'm working on, so remove some cruft
    [components.scad, frame-left.scad, frame-solo.scad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]
2023-09-01 create a top left (overhang) lever panel
    this replaces the left-adjusted inset panel, which I didn't use anyway,
    and starts normalizing the overhang panels more
    [top-panel-left-lever.scad]
2023-09-01 more top panel with overhang options
    left/middle/right/solo is the overhang stuff, will need to rename the
    inset ones at a later point
    [top-panel-middle-dir_arc-plus-w-30mm-with-mount.scad, top-panel-middle-dir_arc-plus-w-30mm.scad, top-panel-right-sega-2p-plus-one.scad]
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2023-09-03 decorative plate for a neutrik D mount
    this is used for the outside of an ethercon, for instance
    [misc-24mm-hole-neutrik-d-plate.scad]
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2023-09-07 with the frame redesign, we can use 16mm M4s
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2023-09-08 break up the sega 2P layout into parts
    messing with something that may never see the light of day, but no harm
    in doing this
    [components.scad]
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2023-09-08 remove more magic numbers, top plate is a derivative of base frame dimensions
    [components.scad]
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2023-09-11 modularize the directional arc part of the 24mm all buttons layout
    this was for a failed experiment, but it's probably good to do this
    regardless
    [components.scad]
2023-09-11 tighten up the inner hole a bit, to no noticeable detriment
    [misc-dustwasher-lsx-nobi.scad]
2023-09-11 change 30mm dir_arc layouts to be based on the thumb position
    this will hopefully make some moving of stuff around a bit easier
    [components.scad]
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2023-09-12 correct hardware notes, since v2 the M4 standoffs are 45mm
2023-09-13 don't mirror, mostly duplicate the left frame components into right frame
    doing a naive mirror meant the neutrik D mount holes were in the wrong
    spot. fine for a 20mm + plate mount, but not good for any actual
    component
    [frame-right.scad]
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2023-10-04 add lever + 6 30mm button sega 2P layout panel
    a bit tight but totally possible
    [misc-decorative-plate-sega-2p-6-button.scad]
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2023-11-09 scoot the button layouts down a bit
    this gives a bit more space at the front, mostly so that the decorative
    plate doesn't hang over the edge of an inset panel
    [components.scad]
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2023-11-15 fix dustwashers by scaling them based on the plate hole
    [components.scad, misc-dustwasher-jlf.scad, misc-dustwasher-lsx-nobi.scad]
2023-11-16 correctly refer to the frame wall as per edge
    [components.scad]
2023-11-16 correctly refer to the plate overhang as per edge
    [components.scad]
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2023-11-23 bring the frame Z back to 55mm, for taller levers
    50mm - 10mm of panels was fine for some levers but not enough for the
    LSX-NOBI, which I personally have a number of. I can't vet every lever
    in existence, but I know at least that this was a problem that is solved
    by adding 5mm, which seems like a fair trade and not a huge difference
    in the final product.
    this also helps the fact that at 40mm internal, some buttons + wiring
    harnesses were getting pretty tight, mostly relevant at the frame
    connection point where the inner bottom panel isn't a basin. this should
    help that too.
    additionally this has us go back to the 45mm M4 standoff recommendation,
    which kinda sucks because it seems like 40mm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
    [components.scad, parameters.scad]
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2024-02-12 grow the frame, remove the bottom panel basin
    the bottom panel had a basin or tray to make room for taller levers,
    namely the Seimitsu LSX-NOBI that I really like. per its specs, the
    lever needs 43.70mm internally, and the old values were too tight (55mm
    - 19mm from panels - 2mm from lever plate = 43) so the bottom panel was
    arbitrarily given a sunken portion (somewhat arbitrarily 2.5mm) to
    compensate at the time, because I already had frames printed.
    adding 2mm to the frame Z covers the difference (57mm - 10mm - 2mm =
    45mm) and thus we don't need the bottom panel hack anymore. I also
    suspect the bottom panel basin was slightly affecting it structurally,
    so this may help that.
    Signed-off-b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
    [bottom-panel-inset.scad, parameters.scad]
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2024-02-13 fix imports of the overhang panels following renames
    [bottom-panel-overhang-left.scad, bottom-panel-overhang-middle.scad, bottom-panel-overhang-right.scad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]
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2024-02-15 fix an old math mistake with the spacing of 24mm aux buttons
    their cutout for the screw nut was giving too much space, which spread
    them out too much on the frame walls. this should fix it, the nuts for a
    Crown SDB-202 or a Seimitsu PS-14 still fit anyway
    [components.scad, frame-left.scad, frame-right.scad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]
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2024-02-18 bevel all the top edges of the frame
    I didn't think I'd want this, but playing with it... yeah. it's a good
    idea.
    [components.scad]
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2024-02-19 correct the hole for the panel-to-frame post
    made it too small accidentally, which explains why I got test prints
    stuck :p
    [components.scad]
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2024-02-22 fix the blown up demo and update it for the docs
    [blown-up-demo.scad]
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2024-03-01 frames: re-bevel the bottom and top, center buttons
    this undoes my work to simplify the bottom of the frame and move button
    holes in the frames accordingly. the top and bottom are now symmetrical
    in terms of their bevel, and the buttons are centered. this will make
    the print of the frame difficult again, but I have an upcoming change to
    modularize the frame walls and that will print far better, so I'm
    thinking this is what I want. testing ongoing
    This reverts commit ed031b9308b062b8900a40851dafac5f18aaa535.
    This reverts commit f90fc095e04b46073f33681b6cbe94b3ac421256.
    [components.scad, frame-left.scad, frame-middle.scad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]
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2024-03-03 use the same plate with posts for the bottom panel
    this makes the bottom panels have posts, now that the frame is looking
    like it will be composed of parts where printing the column hole in this
    fashion is not a problem
    [components.scad]
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2024-03-04 modularize the frame into separate wall pieces
    this provides a system for interlocking frame walls as separate pieces,
    rather than a whole frame box as one piece. the primary motivation for
    this was to improve print quality. these pieces can be printed flat side
    down, meaning improvements due to:
    1. printing the box required the long, thin bottom to be the side on the
    print surface, which meant shrinkage force would curl the corners
    with essentially no remedy outside of bed adhesive
    2. printing the box bottom up created poor circles for the button holes,
    sometimes bad enough to be a visible problem, as well as making small
    flow glitches to stand out (especially on non-matte PLA)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
    [frame-piece-bottom-left-or-right.scad, frame-piece-interconnect.scad, frame-piece-side.scad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]
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2024-03-06 better parameterize frame bevel based on frame_bevel_height
    replace hardcoded values creating the 45 degree bevel with the parameter
    itself, so that htis is a bit more flexible in the future
    [components.scad]
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2024-03-09 correct name of the extra extended side piece
    [frame-piece-side-extended-to-bottom.scad]
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2024-04-04 don't recommend fiddling with the initial layer height/width
    doesn't seem to be any real gain in changing them, having done more
    prints with those settings and with stock settings.
2024-04-04 remove the frame posts from panels, more trouble than they're worth
    the panels had posts that would drive into the frame column (the frame
    column needing to be a bit wider at the top and bottom accodringly).
    this was an attempt to assist the friction fit of the whole stick in
    tandem by having the panels contribute to the position and rigidity of
    the frame pieces. in practice I think this didn't really contribute
    anything major to that problem, and instead made the panels hard to
    connect, and way harder to remove, while also having a visual defect in
    that the panels were usually separated slightly due to having to fit
    exactly in the frame columns.
    this goes back to the old design where the b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
    [components.scad]
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2024-04-22 update the blown up demo, now with frame pieces
    [blown-up-demo.scad]
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2024-05-19 a new stand, far simpler and smaller than the old
    this is basically just a little wedge to display the stick on. I really
    like using three since they're not secured to anything, but I might make
    a plate to put them in next, for a bit more stability
    [stand.scad]
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2024-05-30 leave a section of full frame after a neutrik cutout
    the previous cutout ran the height of the interior, meaning that if you
    looked straight down a top panel edge, if the fit wasn't perfect, you
    could see some gaps, as the lip that the panel was resting on had gaps
    in it. this eliminates that, and makes the pieces with neutrik cutouts a
    bit more stable, by just shortening the cutout box and retaining a
    little lip for the panels across the whole box
    slightly harder to get around with buttons that way, but definitely a
    net improvement
    [components.scad]
2024-06-17 add a shiokenstar layout and top panels
    I didn't use this in a build, but the panels work. there might be some
    misalignment with the interconnect, still, but I'm thinking of redoing
    that piece anyway. I think these files are good at least.
    [components.scad, top-panel-inset-shiokenstar-left.scad, top-panel-inset-shiokenstar-right.scad]
2024-06-17 make a base for the little stand things
    for stability, could be decorated more in the future, that kind of
    thing, but this works right now so I'll commit it before I go breaking
    things
    [stand-base.scad]
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2024-06-19 fix the blown up demo and move it to a demo/ dir
    [blown-up-demo.scad]
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2024-06-19 rename box-style frame pieces to be explicitly for boxes
    I'm going to need to duplicate and edit the top/bottom pieces in
    order to create better extended pieces, so this moves them into
    something explicitly-named. next commit will fix the extended pieces
    [all-together-demo.scad, blown-up-demo.scad, frame-piece-interconnect.scad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]
2024-06-19 fix the extended pieces, sans 45 degree box corner
    box pieces having a 45 degree cut for the corners looks very nice, and
    works well, but the cut interferes with the extended piece options, so
    this reuses the pieces to take ones with the 45 degree lip cut off,
    which would be combined with the flush extended pieces, much like how
    things used to work for these pieces before I made the box pieces use
    said cut.
    this also commits a demo of combining everything extended-style
    phew
    [all-together-demo-extended.scad, frame-piece-side-extended-to-bottom.scad, frame-piece-side-extended.scad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]
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2024-06-22 favor symmetry in the front/back and side wall windowed pieces
    I think the lack of symmetry led to a varying amount of force being
    applied when joined with the interconnect. take for instance:
    OUTER INTER INNER
    INTER INTER INTER
    INNER INTER OUTER
    if OUTER (the "windowed" piece, the outside wall + one half of the
    mounting column) is on top on the left side and on the bottom on the
    right side, and INNER (the inner wall, the one that floats around
    relative to the outer wall) vice versa on the other side, the two pieces
    side by side would not create a clean line --- left would be ~0.5mm
    lower than the right.
    if there was a way to clamp these down relative to each other, the
    problem migh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
    [front-or-back-inner-wall.scad, side-inner-wall.scad]
2024-06-24 rewrite "plates" as two separate plates
    could these be broken up? yes. but this .scad was never used AFAIK, so
    I'm just going to repurpose it
    [decorative-plate-dir_arc-plus-w-30mm-and-sega-2p-plus-one-plates.scad]
2024-06-24 update build blown up demo and example photo
    [blown-up-demo.scad]
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2024-06-25 fix alignment of a bottom overhang panel in the demo
    [blown-up-demo.scad]
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2024-07-07 fix an issue with frame wall + small button screw-in space
    [components.scad]
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2024-07-12 add some windowed frame pieces to go with extended sides
    also a demo for them, though I didn't add the inside walls to the demo
    [all-together-demo-extended-with-windows.scad, front-or-back-clean-for-extended-side-windowed-horiz-stripes.scad, front-or-back-clean-for-extended-side-windowed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]
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2024-09-15 break out the angled dir_arc + W decorative plate
    there's a decorative plate angled plate that includes the sega 2P + 1
    buttons and dir_arc + W buttons as separate pieces in the same model.
    this is a historical artifact that I will fix at some point, but for now
    at least, here is the dir_arc + W split out
    [decorative-plate-dir_arc-plus-w-30mm-plate.scad]
2024-09-15 create a panel with three aux buttons in a tight cluster
    the idea of this is to have Select, Home, and Start buttons accessible
    via this panel away from the action panels, and the action pannels have
    the L3, TP, and R3 buttons in the Sega 2P 11 layout, and then there is
    no need for buttons on the back of the q2009 enclosure. I don't think
    this would get used for any reason other than q2009 so it lives there.
    [components.scad, panel-three-aux-buttons.scad]
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2024-09-17 gitignore .stl files
    why didn't I do this aeons ago!?
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2024-09-24 another aux panel, this with a hole for a rocker switch
    I realized pretty late in the build here that I didn't have a way to
    access the Fn switch, so I'm just going to try putting it away at the
    top back for now
    [panel-three-aux-buttons-and-rocker-hole.scad]
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2025-03-05 use the derived frame piece x dimension to build front/back
    this saves one operation and removes a bit of the artifacts. didn't seem
    to help the 2-manifold stuff I was looking at, but this is slightly
    clearer anyway?
    [front-or-back.scad, parameters.scad]
2025-03-05 use the derived frame piece y dimension to build side
    as in previous commit, this simplifies the build of the side frame piece
    a bit. notably on this one, the preview of the piece is more performant,
    so I'm thinking this is a good move. the object triangle count and
    volume are slightly different (not sure why), but the object dimensions
    are the same
    still didn't get rid of any 2-manifold errors though :(
    [parameters.scad, side.scad]
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2025-03-09 improve on the dustwashers' fit
    the hole is a bit tighter now, made possible by having a bevel on the
    inside for the lever to move
    [dustwasher-jlf.scad, dustwasher-lsx-nobi.scad, parameters.scad]
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2025-03-20 tighten the dustwashers inner hole a bit
    tested on my Nobis and it's still just a hair loose, but maybe that's
    printer tolerances at this point, not inclined to mess with it much
    further. this hole is exactly the radius of the lever shaft, with the
    tapering to allow for it to be moved
    [dustwasher-jlf.scad, dustwasher-lsx-nobi.scad]
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2025-03-20 shrink the radius of the decorative 24mm disc
    it just stands out a bit too much at the default, IMO, considering the
    button is standalone and not part of a 24mm layout where the default is
    nicer
    [decorative-plate-24mm-button.scad, decorative-plate-aux-control-tight-three-button-cluster.scad, decorative-plate-dir_arc-plus-w-30mm-and-sega-2p-nine-rectangl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]
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2025-03-28 fix an issue with decorative plate sizing
    I was taking a hull of the whole button negative shape in many places,
    rather than a hull of the sliced shape, which meant the amount of
    decorative plate beyond the button holes varied depending on the exact
    positioning of how it was sliced. this was brittle in general, but
    more importantly made many plates too big when I cleaned up some code to
    remove an override that I thought was irrelevant --- it was actually
    affecting the overall geometry outside of the slice
    [all-together-demo-extended-with-windows.scad, decorative-plate-24mm-button.scad, decorative-plate-aux-control-tight-three-button-cluster.scad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]
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2025-05-28 rework the OLED mount and add it to a new panel
    [components.scad, lever-and-dir_arc-plus-w-30mm-panel-with-oled.scad, parameters.scad]
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2025-06-01 some fixes and updates to the extended demo
    [all-together-demo-extended.scad]
2025-06-08 add a simple sleeve for a hex spacer that isn't wide enough
    I got a bag of spacers that are not as wide as what I normally use, so
    they rattle around in the post hole and obviously don't help with the
    fit of the completed stick. this sleeve seems to be right for them to
    fill the hole. provided in case it is useful in the future, for myself
    or anyone else
    [m4-hex-spacer-sleeve.scad]
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2026-01-04 fixing object names; these pieces are *not* for extended sides
    the object that made them "for" extended sides actually didn't do
    anything, either, so they've been removed
    [front-or-back-windowed-backslashes.scad, front-or-back-windowed-forwardslashes.scad]
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2026-01-04 cut some volume off of the front or back pieces where they touch sides
    there is a printing issue where a fat couple layers jut out a bit on the
    edge where the front or back piece would touch a side piece or another
    front or back piece, making them not connect that flushly. this removes
    a bit in order to let that fat layer be in a gap instead
    [all-together-demo.scad, blown-up-demo.scad, front-or-back-aux-and-neutrik.scad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]
2026-01-06 use a smaller frame bevel in order to improve print quality
    the bevel was big and looked nice, but the number of layers might have
    been contributing to reduced print quality and increased pull on the
    corners of the pieces printed face down (so bevels going out as layers
    go up). this reduces the size of the bevel in an attempt to make the
    problem less pronounced. hopefully.
    there was also a bunch of weird math in the trapezoid frame pieces that
    relied on the bevel size in broken ways, so the pieces have been
    simplified a little bit to work right and not be affected by that
    otherwise unrelated parameter.
    [front-or-back-trapezoid.scad, parameters.scad, side-trapezoid-extended-to-front-trapezoid.scad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]
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2026-04-28 add a model for a pin that fits snugly between frame pieces
    this can be an alternative to buying spacers of the proper size.
    using the printed pin reduces the weight of the build, but IME the
    friction fit of the pin is good and still leads to a sturdy frame.
    care needs to be taken to make sure that screwing the bolts into the pin
    doesn't shear the pin or (more likely) strip the screw hole, but so far
    it has not been a problem bad enough to have the stick disassemble or
    anything like that.
    [frame-assembly-pin.scad]
2026-04-28 add a simple shim part, for panel to frame connection points
    I have found it handy to sometimes have a little shim inside the
    enclosure at points where, due to minor warping, or scrap, or just
    printer variance, the panel isn't completely flush with the frame, and
    applying pressure bends or "pops" it slightly. stick the shim in to
    eliminate the bend at that point, and things feel more stable.
    [shim.scad]
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2026-05-01 make the pin a bit tighter fit and better parameterized
    [frame-assembly-pin.scad]
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
